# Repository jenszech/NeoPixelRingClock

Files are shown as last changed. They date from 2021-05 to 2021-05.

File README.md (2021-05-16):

# NeoPixelRingClock





Dieses Projekt verwendet die Adafruit NeoPixel-Bibliothek, um einen 60-LED-NeoPixel-Ring als Uhr zu steuern.

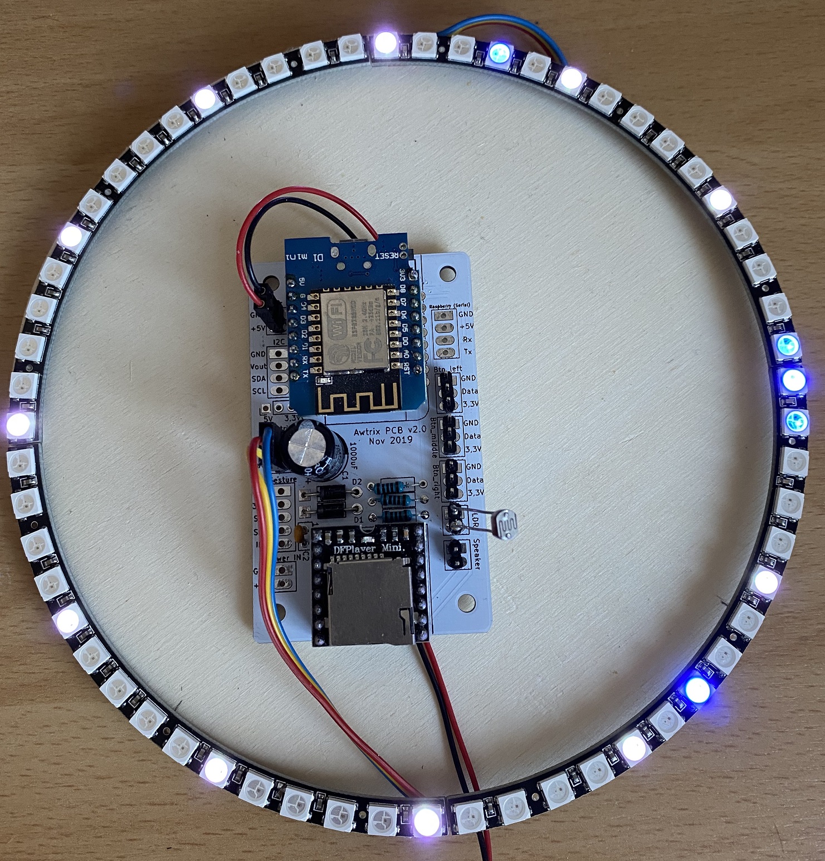
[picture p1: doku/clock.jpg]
Hardware Beispiel


## Features
* Anzeige der Uhrzeit durch grüne LEDs
* Anzeige von Stundenmarkierungen (weiße LEDs)
* Helligkeitssensor wechselt zwischen Day & Night Modus
* WebServer auf dem ESP zeigt die aktuelle Configuration & Uhrzeit

## Geplante Features
* Einstellen einer Alarmzeit
* Die Alarmzeit wird durch eine rote Markierung zusätzlich zur Uhrzeit anzeigt
* Rest / HTML API zum steuern / einstellen der Uhr per Smartphone
* Dokumentation per Fritzing Hardware Beispiel

Für geplante Features und Änderungen siehe [CHANGELOG.md](https://github.com/jenszech/NeoPixelRingClock/blob/master/CHANGELOG.md)

# Dokumentation

## Software

Enter `https://arduino.esp8266.com/stable/package_esp8266com_index.json` into *Additional Board Manager URLs* field. Open Boards Manager from Tools > Board menu and find *esp8266* platform and install Version 2.7.4

### Erforderliche Bibliotheken

Über Bibliotheksmanager installieren
* NTPClient  - by Fabrice Weinberg - Version 3.2.0
* Adafruit NeoPixel - by Adafruit - Version 1.1.7
* WifiManager - by tzapu, tablatronix - Version 0.16.0
* Time - by Michael Margolis - Version 1.6.0
  - Beispiele unter TimeLib by Paul Stoffregen
    https://github.com/PaulStoffregen/Time
* EspHtmlTemplateProcessor - by Patrick Lapointe - Version 1.2.1
* NeoPixelBus - by Micheal C. Miller - Version 2.5.7 

Manuell zu installieren

* ESP8266FS - https://github.com/esp8266/arduino-esp8266fs-plugin

Wenn der EPS8266FS erfolgreich installiert wurde, muss einmal im "Tools" Menü die Funktion "ESP8266 Sketch Data Upload" ausgeführt werden. Falles Probleme dabei gibt, vorher einmal die USB Verbindung zum EPS trennen und wieder anschließen.

## Hardware

###  Erforderliche Teile

* 4 x Neo Pixel 1/4 Ringe (je 15 LEDs)  [Link](https://de.aliexpress.com/item/4000102576864.html?spm=a2g0s.9042311.0.0.48fe4c4doc7WPP) 
* 1 x ESP8266-Modul. Ich benutze den WeMos D1 mini
* 1 x LDR GL5528
* 1 x 1k Ohm Widerstand
* 1 * 1000uF 10V Kondensator
* 1 * 5V Netzteil >= 3A [Link1](https://www.amazon.de/gp/product/B01HRR9GY4/ref=ppx_yo_dt_b_search_asin_title?ie=UTF8&psc=1) [Link2](https://de.aliexpress.com/item/32803238789.html?spm=a2g0s.9042311.0.0.48fe4c4doc7WPP)

### Hardware Layout

Erstellt mit Fritzing https://fritzing.org/

Erforderliche Fritzing Bibliotheken: https://github.com/adafruit/Fritzing-Library

Layout dieses Projektes als Fritzing Datei: [HWLayout](https://github.com/jenszech/NeoPixelRingClock/blob/master/src/Layout/HWLayout.fzz)

#### Steckplatine

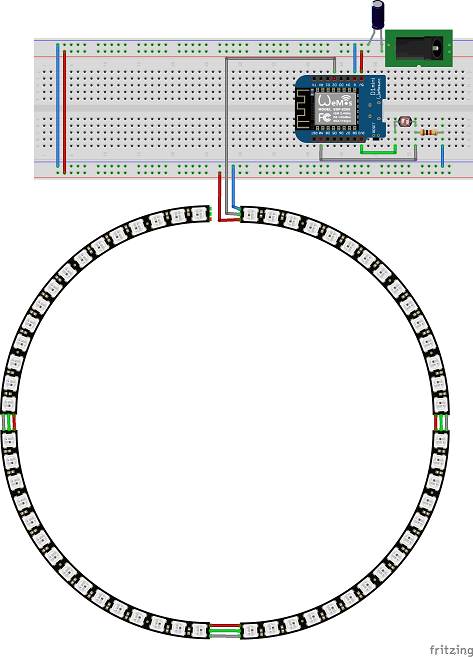
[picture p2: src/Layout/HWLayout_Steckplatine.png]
Steckplatine


#### Schaltplan

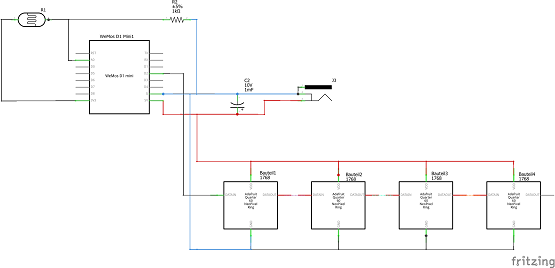
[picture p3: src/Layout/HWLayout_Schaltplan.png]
Schaltplan


# Sonstiges

## Contributing

Please read [CODE_OF_CONDUCT.md](https://github.com/jenszech/NeoPixelRingClock/blob/master/CODE_OF_CONDUCT.md) for details on our code of conduct, and the process for submitting pull requests to us.

## Versioning

We use [SemVer](http://semver.org/) for versioning. For the versions available, see the [tags on this repository](https://github.com/your/project/tags).

## Authors

- **Jens Zech** - *Project owner* - [GitHub Profil](https://github.com/jenszech)
- Florian Adam - Contributor- [GitHub Profil](https://github.com/xfadam)

See also the list of [contributors](https://github.com/jenszech/NeoPixelRingClock/contributors) who participated in this project.

## License

This project is licensed under the MIT License - see the [LICENSE.md](https://github.com/jenszech/NeoPixelRingClock/blob/master/LICENSE.md) file for details

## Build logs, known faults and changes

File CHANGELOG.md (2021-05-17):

# Roadmap
## Geplante Features
* Einstellen einer Alarmzeit
* Die Alarmzeit wird durch eine rote Markierung zusätzlich zur Uhrzeit anzeigt
* Rest / HTML API zum steuern / einstellen der Uhr per Smartphone
* ~~Dokumentation per Fritzing Hardware Beispiel~~

## Changelog

### 1.0.x

* Auslagern des LdrSensors in eine eigene Klasse

### 1.0.2

* Umstellung auf VSCode
* Auslagern der PixelSteuerung in eine eigene Klasse

### 1.0.1

* Hardware Layout als Fritzing Entwurf hinzugefügt
* Lizenz Files & CodeOfConduct hinzugefügt

### 1.0.0

* Erste lauffähige Version der Uhr
* Anbindung an den NTP Zeitserver
* OverTheAir Update implementiert
* HTTP Interface mit Static HTML 

### 0.0.1

* Initiales Projekt Setup

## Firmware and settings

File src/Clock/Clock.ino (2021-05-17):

/*
  Project: WS2812 Ring LED clock with NTP server using ESP32
  Board: Wemos D1 Mini 
  Author: jzech@gmx.de
 */

#include <arduino.h>

// My secret stuff (eg WiFi password)
#include "config.h"

// How we connect to your local wifi
#include <ESP8266WiFi.h>
#include <ESP8266mDNS.h>

// UDP library which is how we communicate with Time Server
#include <ArduinoOTA.h>
#include <NTPClient.h>
#include <TimeLib.h>
#include <WiFiUdp.h>

// Include WebServer Lib
#include <ESP8266WebServer.h>
#include <FS.h>  // muss vor <detail\RequestHandlersImpl.h> stehen (s. Hinweis im Anschluss)
#include <EspHtmlTemplateProcessor.h>

#include "NeoPixelLib.h"
#include "LdrLib.h"

WiFiUDP ntpUDP;
ESP8266WebServer webserver(80);
EspHtmlTemplateProcessor templateProcessor(&webserver);
NTPClient timeClient(ntpUDP);

// forward declarations
void serialTimeLog();
void setupNTP();
void setupNeoPixel();
void displayBasicClock();
time_t updateTimeByNTP();

//-----------------------------------------------------------------------------
// MAIN   MAIN   MAIN   MAIN   MAIN   MAIN   MAIN   MAIN   MAIN   MAIN   MAIN
//-----------------------------------------------------------------------------

NeoPixelLib neoPixel(_PIXEL_NUM, _PIXEL_PIN);
LdrLib ldrSensor(_LDR_PIN,  _LDR_TRESHOLD);

void setup() {
    Serial.begin(115200);
    connectToWifi();
    setupOTA();
    setupNTP();
    neoPixel.setupNeoPixel();
    setupWebServer();
}

long currentMillis = 0;
long previousMillis = 0;
int isDarkMode = false;

void loop() {
    currentMillis = millis();
    isDarkMode = ldrSensor.isDark();

    //Update NeoPixel Display
    neoPixel.loopPixelUpdate(isDarkMode);

    //Debug Output every 60sec.
    if (currentMillis - previousMillis > 60000) {
        previousMillis = millis();
        serialTimeLog();
        ldrSensor.printSerialLog();
    }

    loopWebServer();
    loopOTA();
    delay(_PIXEL_UPDATE_INTERVAL);  // Pause before next pass through loop
}

//-----------------------------------------------------------------------------
// NTP Methods
//-----------------------------------------------------------------------------

// Establish a WiFi connection with your router
void connectToWifi() {
    Serial.print("\nConnecting to: ");
    Serial.println(_mySsid);
    WiFi.begin(_mySsid, _myPassword);

    // Try to connect 4 times a second for X seconds before timing out
    int timeout = _wifiTimeOutSeconds * 4;
    while (WiFi.status() != WL_CONNECTED && (timeout-- > 0)) {
        delay(250);
        Serial.print(".");
    }

    // Successful connection?
    if (WiFi.status() != WL_CONNECTED) {
        Serial.println("\nFailed to connect, exiting");
        // Set some LED failure here, for example
        delay(1000);
        return;
    }

    Serial.print("\nWiFi connected with (local) IP address of: ");
    Serial.println(WiFi.localIP());
}

void setupNTP() {
    Serial.print("\nNTP startet with Offset: ");
    Serial.println(_ntpTimeOffset);
    timeClient.begin();
    timeClient.setTimeOffset(_ntpTimeOffset);
    timeClient.setUpdateInterval(_ntpUpdateIntervall);
    timeClient.update();
    while (!timeClient.update()) {
        timeClient.forceUpdate();
    }
    setSyncProvider(updateTimeByNTP);
    setSyncInterval(_resyncSeconds);  // just for demo purposes!
    Serial.print("NTP Time: ");
    Serial.println(timeClient.getFormattedTime());
    Serial.print("TimeLib: ");
    serialTimeLog();
    Serial.println(getTimeStr());
}

//-----------------------------------------------------------------------------
// TimeLib Functions
//-----------------------------------------------------------------------------

// resync Method - get Time from NTPClient
time_t updateTimeByNTP() {
    Serial.println("TimeLib resync");
    return timeClient.getEpochTime();
}

String getTimeStr() {
    String timeStr = "";
    time_t t = now();

    timeStr += printDigits(hour(t));
    timeStr += ":";
    timeStr += printDigits(minute(t));
    timeStr += ":";
    timeStr += printDigits(second(t));
    timeStr += " ";
    timeStr += printDigits(day(t));
    timeStr += ".";
    timeStr += printDigits(month(t));
    timeStr += ".";
    timeStr += printDigits(year(t));

    return timeStr;
}

void serialTimeLog() {
    Serial.println(getTimeStr());
}

String printDigits(int digits) {
    // utility for digital clock display: prints leading 0
    if (digits < 10) return "0" + String(digits);
    return String(digits);
}

//-----------------------------------------------------------------------------
// WebServer Methods
//-----------------------------------------------------------------------------
// Create a new web server
void setupWebServer() {
    // Initialize file system.
    if (!SPIFFS.begin()) {
        Serial.println("SPIFFS nicht initialisiert!");
        while (1) {
            yield();
        }
    }
    Serial.println("SPIFFS ok");

    // Start Web Server
    webserver.on("/", handleRootIndex);
    webserver.on("/config.html", handleRootConfig);
    //webserver.serveStatic("/", SPIFFS, "/index.html");
    webserver.serveStatic("/config.html", SPIFFS, "/config.html");
    webserver.onNotFound(notfoundPage);
    webserver.begin();
}

// Handle 404
void notfoundPage() {
    Serial.println("GET not found");
    webserver.send(404, "text/plain", "404: Not found");
}

// Listen for HTTP requests
void loopWebServer(void) {
    webserver.handleClient();
}

void handleRootIndex() {
    templateProcessor.processAndSend("/index.html", indexKeyProcessor);
}
void handleRootConfig() {
    templateProcessor.processAndSend("/config.html", indexKeyProcessor);
}

String indexKeyProcessor(const String& var) {
    Serial.println(var);
    if (var == "CLOCK") {
        return getTimeStr();
    } else if (var == "SSID") {
        return WiFi.SSID();
    } else if (var == "WLAN") {
        return "online";
    } else if (var == "NTPTIME") {
        return timeClient.getFormattedTime();
    } else if (var == "NTPOFFSET") {
        return String(_ntpTimeOffset);
    } else if (var == "NTPUPDATE") {
        return String(_ntpUpdateIntervall);
    } else if (var == "LIBTIME") {
        return getTimeStr();
    } else if (var == "LDRVALUE") {
        return String(ldrSensor.getLdrValue());
    } else if (var == "LDRISDARK") {
        return String(ldrSensor.isDark());
    } else if (var == "LDRTRESHHOLD") {
        return String(_LDR_TRESHOLD);
    }
}

//-----------------------------------------------------------------------------
// OTA Methods
//-----------------------------------------------------------------------------
void setupOTA() {
    Serial.printf("Sketch size: %u\n", ESP.getSketchSize());
    Serial.printf("Free size: %u\n", ESP.getFreeSketchSpace());
    ArduinoOTA.setHostname("myPixelClock");
    ArduinoOTA.begin();
}

void loopOTA() {
    ArduinoOTA.handle();
}

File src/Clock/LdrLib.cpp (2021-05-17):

/*
  LdrLib.h - Library for reading ldr values
  Created by Jens Zech, 2021-05-16.
*/

#include "LdrLib.h"

#include "Arduino.h"

LdrLib::LdrLib(uint8_t pin, uint16_t threshold) {
    _pin = pin;
    _threshold = threshold;
}

bool LdrLib::isDark() {
    int sensorValue = analogRead(_pin);  // read analog input pin 0
    return (sensorValue < _threshold);
}

int LdrLib::getLdrValue() {
    return analogRead(_pin);
}

void LdrLib::setTreshold(uint16_t threshold) {
    _threshold = threshold;
}

void LdrLib::printSerialLog() {
    int sensorValue = analogRead(_pin);  // read analog input pin 0

    Serial.print("LDR: ");
    Serial.print(sensorValue, DEC);
    Serial.print(" => isDark: ");
    Serial.println(isDark());
}

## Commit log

2021-05-16 Add Hardware documentation
    [HWLayout.fzz]
2021-05-16 add vscode arduino config
2021-05-16 HWLayout updated
    [HWLayout.fzz]
2021-05-17 Extract LDR sensor into a class file

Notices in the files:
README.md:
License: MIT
